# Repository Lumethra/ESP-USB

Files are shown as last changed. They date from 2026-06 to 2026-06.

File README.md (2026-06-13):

# ESP-USB

## What is this? 

This is a "wireless" USB-cable for USB devices. It can "wirelessify" (almost) any USB device with only 2 ESP32-S3's. It can be powered by 5V or even by a 3.7V LiPo battery on the senders side (the side with the USB device). I also features a minimal latency of 2ms, or sometimes even less!!!

### Features: 
- send HID-Protocols wirelessly
- pass the HID-Protocol to the PC with tinyusb
- 1 USB-C
- 1 Status-LED
- 3.7V to 5V booster
- 5V to 3.3V converter
- LiPo battery charger and protector
- 2 buttons, boot and reset
- custom USB-C-CC-Pins-handling

---

## Why? 

I got a new keyboard and wanted it to be wireless. It wasnt possible to do this from the firmware side, because it uses a rpi pico 2 as MCU and upgrading it to a rpi pico 2W wont do much because ZMK doesnt like the bluetooth feature of it. So I thought if it was possible to send the HID-reports, which the keyboard is sending constantly over 2.4Ghz, so the wifi bandwith. After some research I found out that the ESP32-S3 features USB-OTG, so it can read these reports and send them over ESP-Now, a custom "wifi" specifically for ESPs. This will reduce latency by alot. 

--- 

## How?

There are 2 ways of making this project. 1 DIY-version and 1 PCB-version. If you have 2 ESP32-S3-Wroom-1 Devboards, feel free to take the DIY road. 

### DIY:

To replicate this project with 2 ESP32-S3-Devkit-C's you simply just need to download the 2 firmwares, the senders and the recievers. The [ESP-IDF-extension](https://docs.espressif.com/projects/vscode-esp-idf-extension/en/latest/index.html) for [VS-Code](https://code.visualstudio.com/) is also required to flash the firmware. Flashing the firmware is also really easy. After sucessfully installing the ESP-IDF-extension, open the firmware of the reciever by going to the top left and selecting file > open folder > and open the folder containing the reciever firmware. Then go to the bottom bar and select UART for the flash method, its the button with the small little star. We also need to specifiy the COM-port of the ESP. Finding that out is OS-specific, but there are also alot of tutorials for this. For the IDF-Target, select ESP32-S3, since thats out device. Now we are almost finished. The last step we need to take is building and flashing the firmware. We can archieve this by clicking the fire icon a bit more on the right. This will build and flash the firmware. Now repeat this exact precess with the sender and you will have a working ESP-USB-cable. 

<details>
  <summary>
    <h4>TL;DR</h4>
  </summary> 

  - download VS-Code and the ESP-IDF extension
  - download the firmware
  - open the folder with the firmware
  - select UART for flash method
  - select the COM-Port
  - select ESP32-S3 as device
  - press the small fire to build and flash
  - repeat for 2nd device
</details>

### PCB: 

When deciding to use my custom PCB, which is smaller, we need to first order it. JLCPCB for example is a pretty good option. After having it in person, we need to connect it to our PC and hold the boot button while pressing the reset button once. After pressing the reset button we can release the boot button for now. This will set the ESP into download mode and we can flash it exactly like a ESP32-S3-Devkit-C. How this works is explained in the DIY-section above. After flashing both the reciever and the sender we need to decide on a way to power our sender (the one on the USB device side), because it needs to power our USB-device. There are 2 ways, one is connecting a LiPo battery and the other is using 2 of the 4 test pads. The LiPo battery is straight forward, but for the test pads you need 2 cables and a usb breakout board to power the pcb with 5V and GND. After all these steps you can have fun with your wireless usb cable then. 

<details>
  <summary>
    <h4>TL;DR</h4>
  </summary> 

  - order PCB
  - hold boot button
  - press reset button while boot button is hold down
  - release boot button
  - flash firmware (look [here](https://github.com/Lumethra/ESP-USB/blob/main/README.md#diy))
  
</details>

---

### Version differences

### V1:

  - small and compact
  - expensive for PCBA
  - components are exact the same as V2

### V2:

  - slightly bigger than V1
  - waaay cheaper
  - components are exact the same as V1

### V3:

  - biggest
  - adding USB-A-female connector
  - cheaper LED to save cost

---

## Renders

| PCB V1 |
| --- |
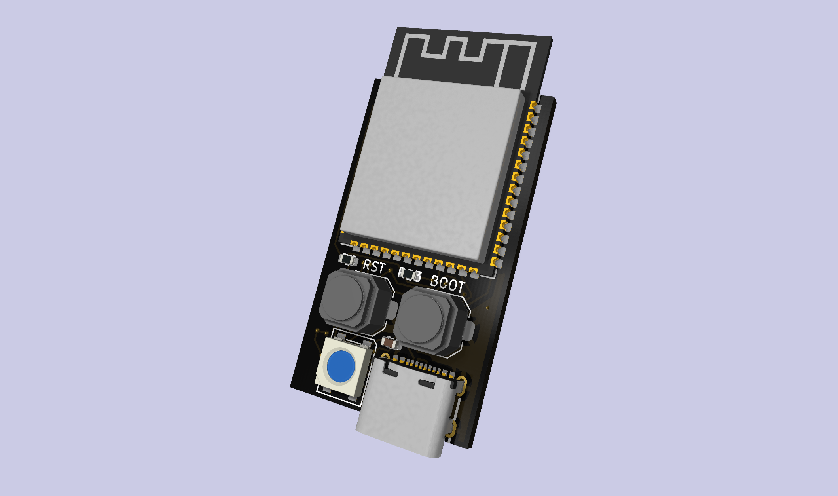
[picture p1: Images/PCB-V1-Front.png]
ESP-USB Front with Components
|  |
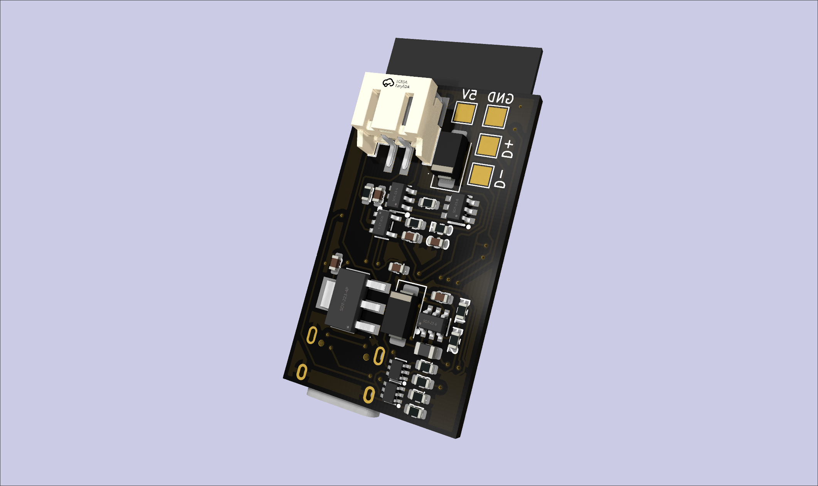
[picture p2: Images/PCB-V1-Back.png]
ESP-USB Back with Components
|  |

| PCB V2 |
| --- |
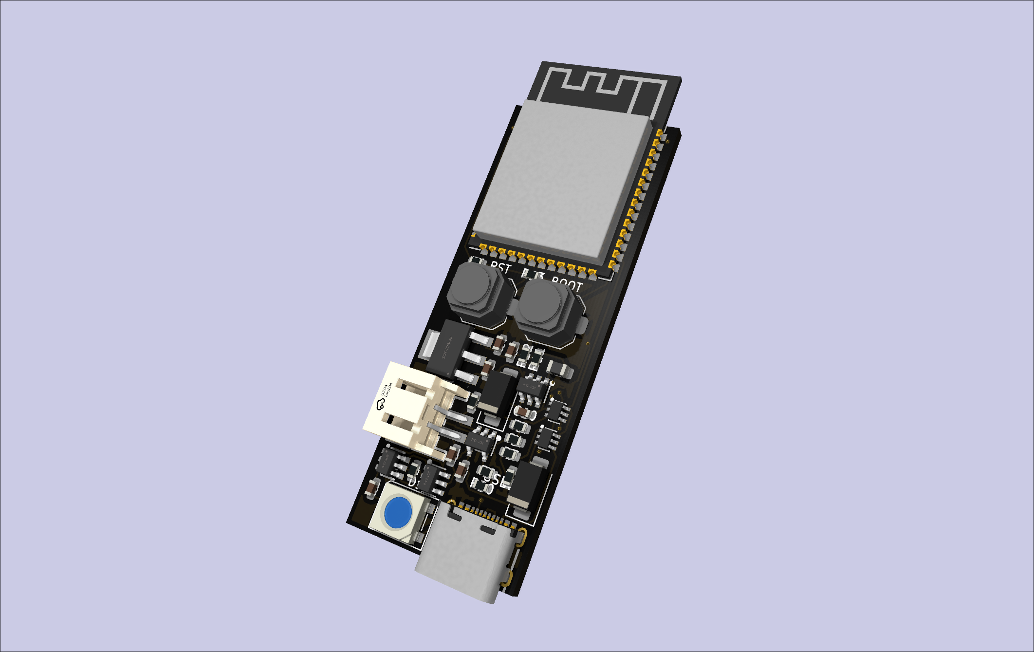
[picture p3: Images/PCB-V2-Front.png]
ESP-USB Front with Components
|  |
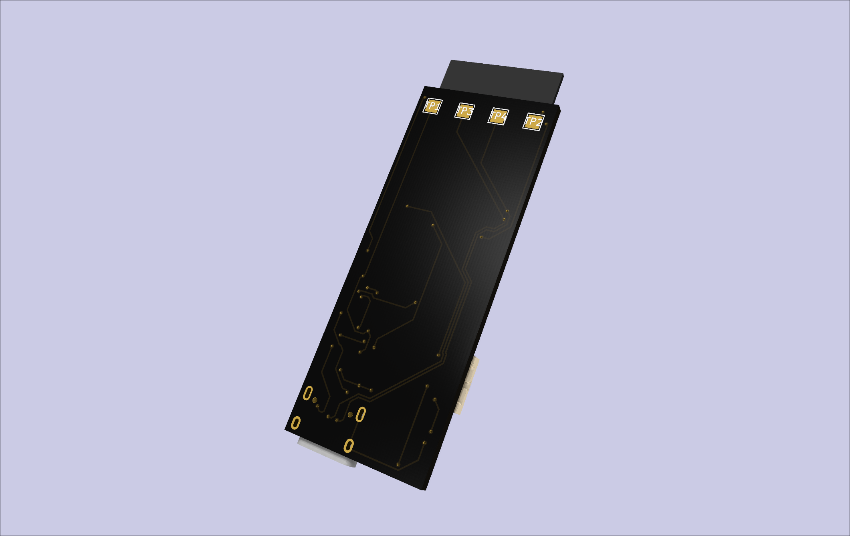
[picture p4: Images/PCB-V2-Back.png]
ESP-USB Back with Components
|  |

| PCB V3 |
| --- |
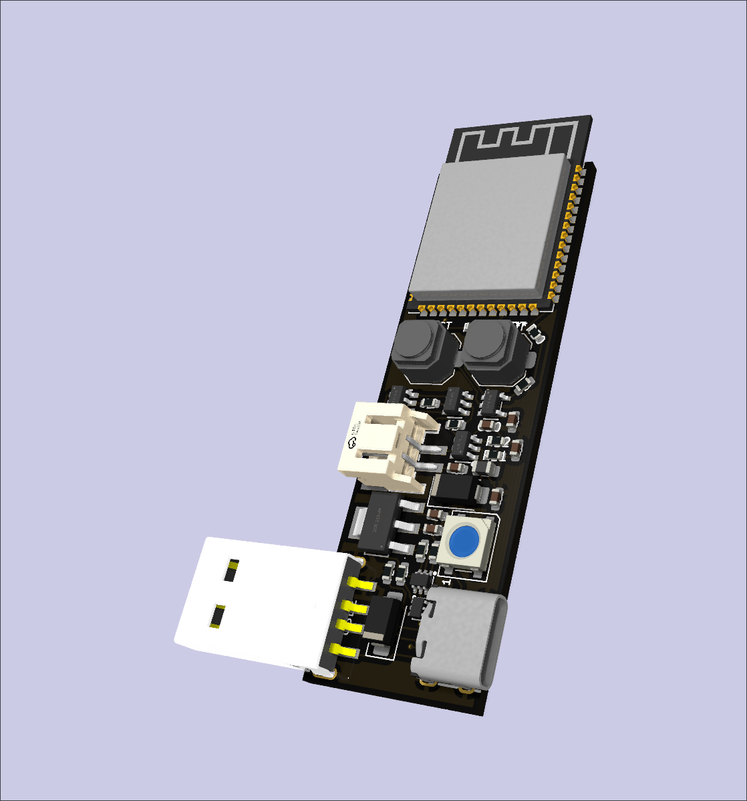
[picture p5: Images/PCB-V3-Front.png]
ESP-USB Front with Components
|  |
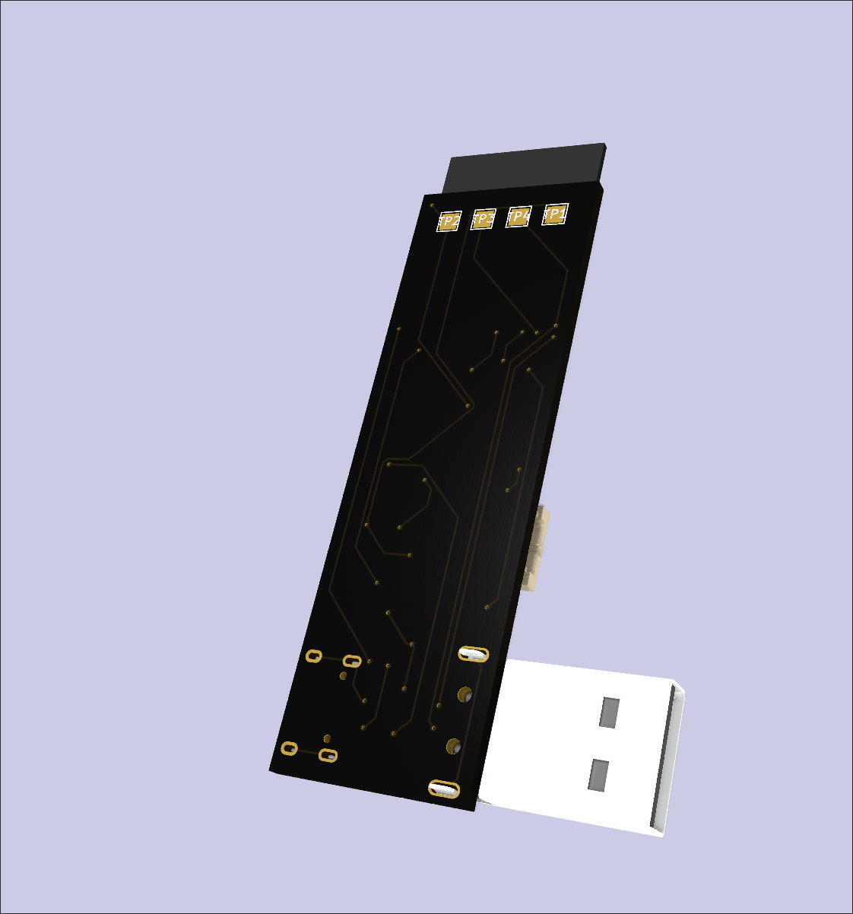
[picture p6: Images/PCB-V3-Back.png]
ESP-USB Back with Components
|  |

---

## PCB + Schematics

| PCB V1 |
| --- |
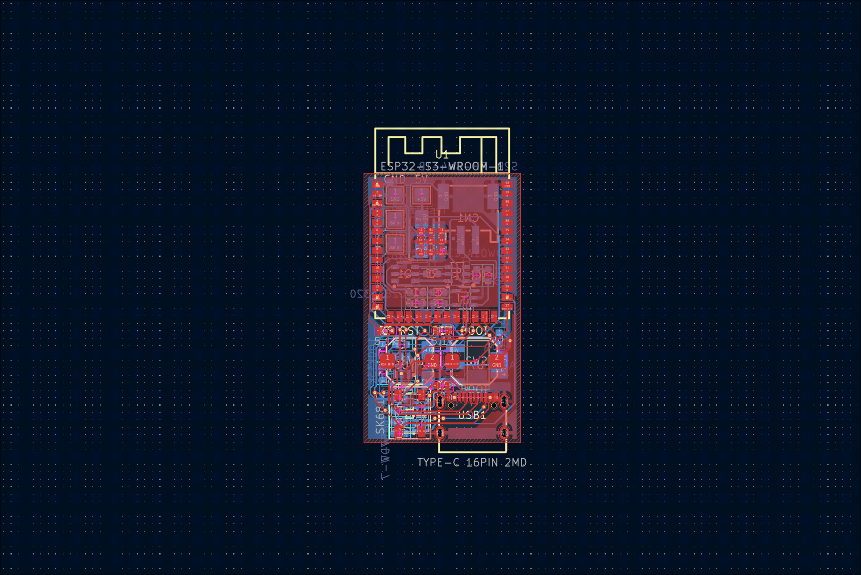
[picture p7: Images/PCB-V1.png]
|  |

| PCB V2 |
| --- |
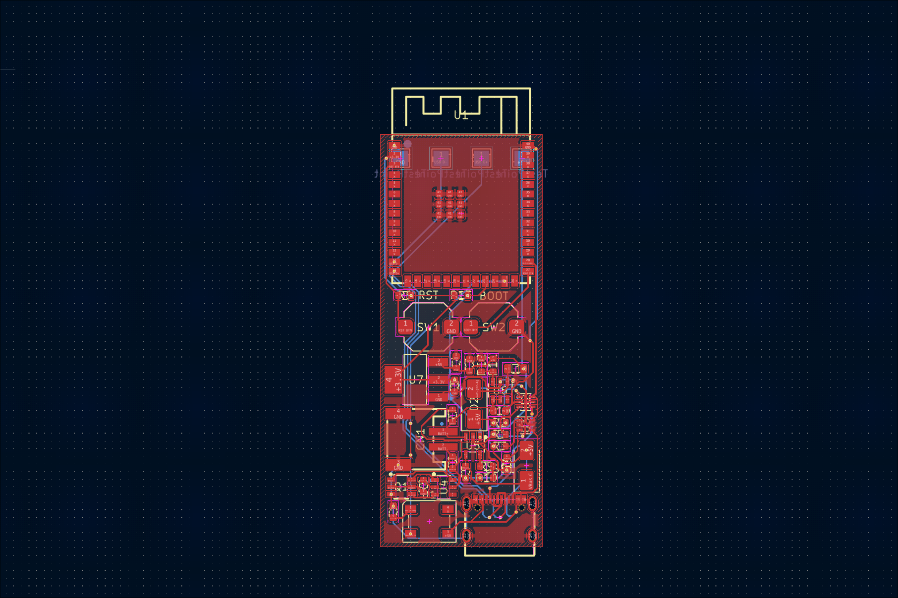
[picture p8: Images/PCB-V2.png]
|  |

| PCB V3 |
| --- |
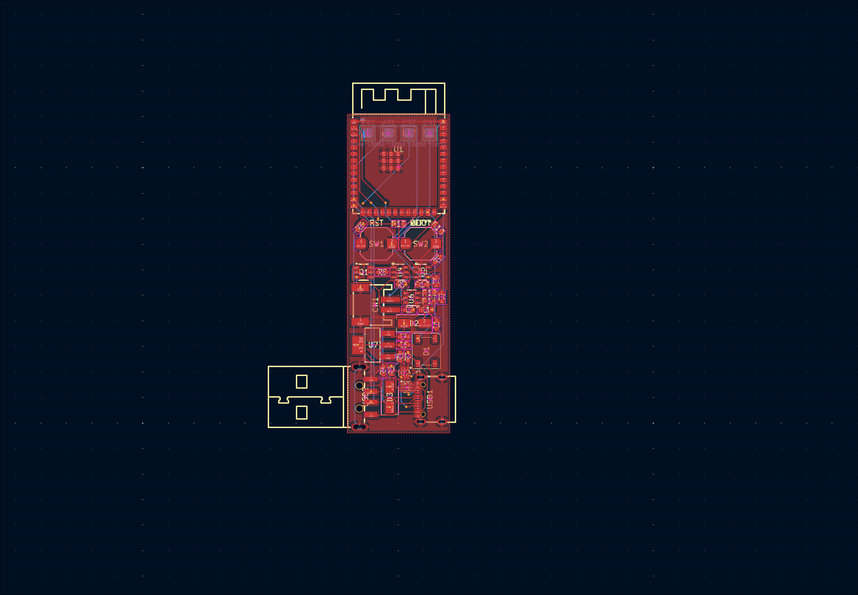
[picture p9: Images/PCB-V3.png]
|  |

| Schematics V1/V2 |
| --- |
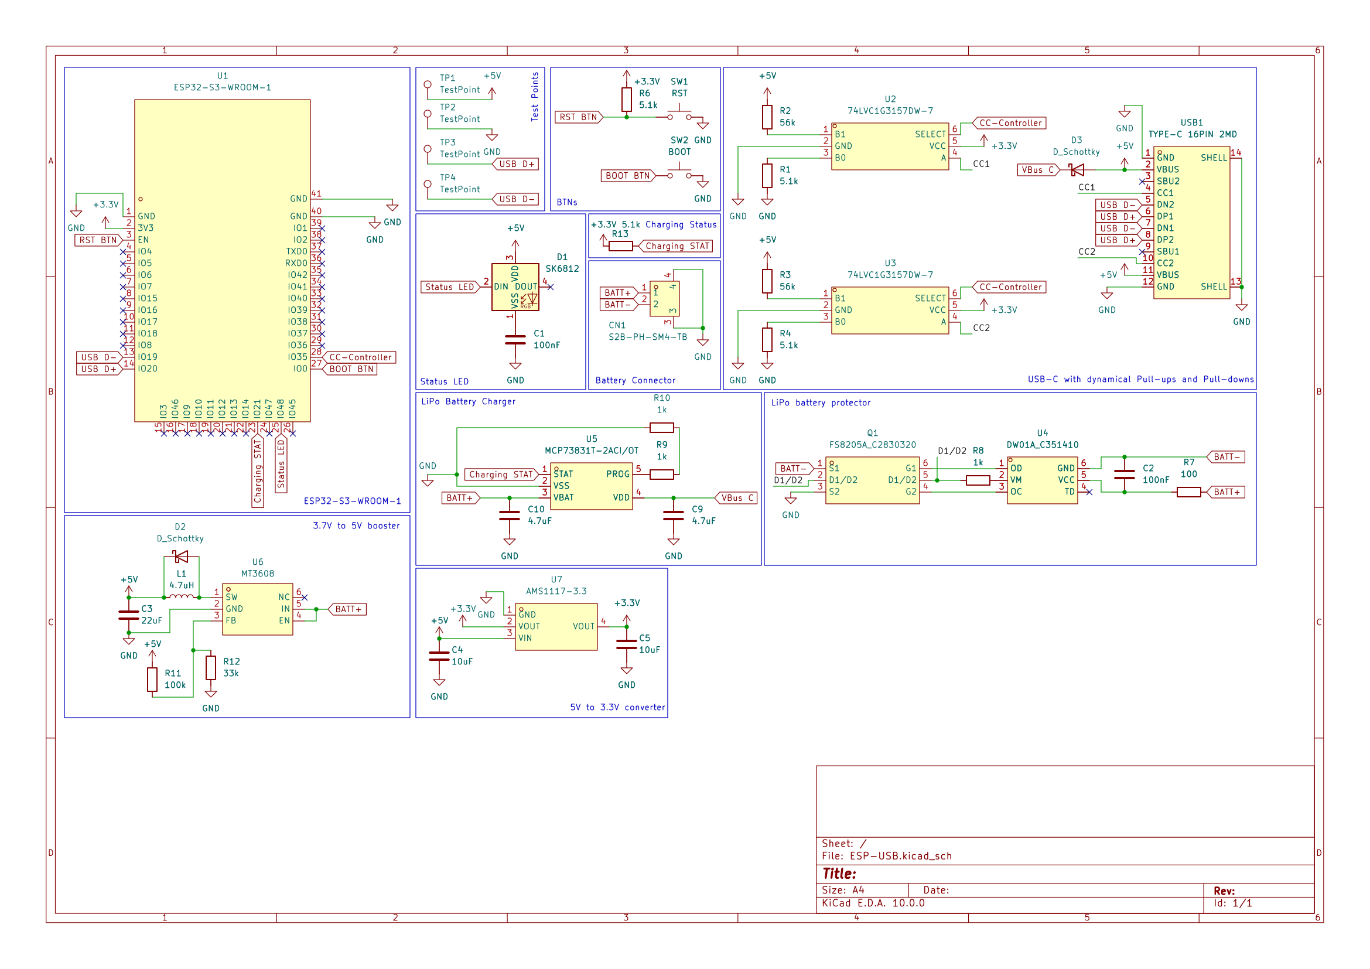
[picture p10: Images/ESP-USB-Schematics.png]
ESP-USB Schematics
|  |

| Schematics V3 |
| --- |
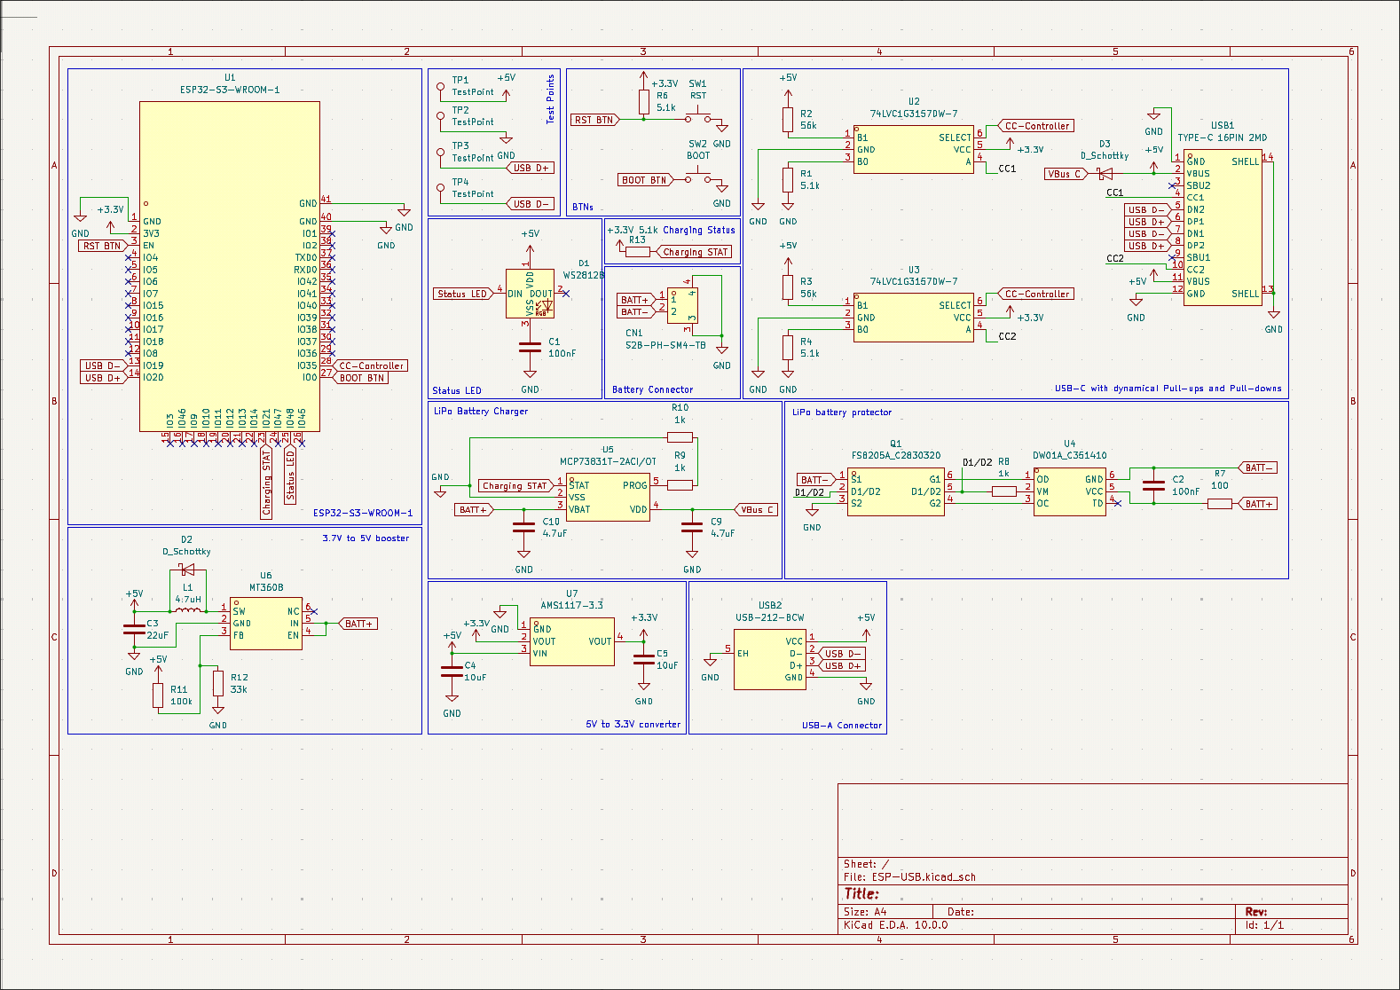
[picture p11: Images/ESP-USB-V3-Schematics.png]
ESP-USB Schematics
|  |

---

<details>
  <summary>
    <h2>Zine</h2> 
  </summary>

| Zine |
| --- |
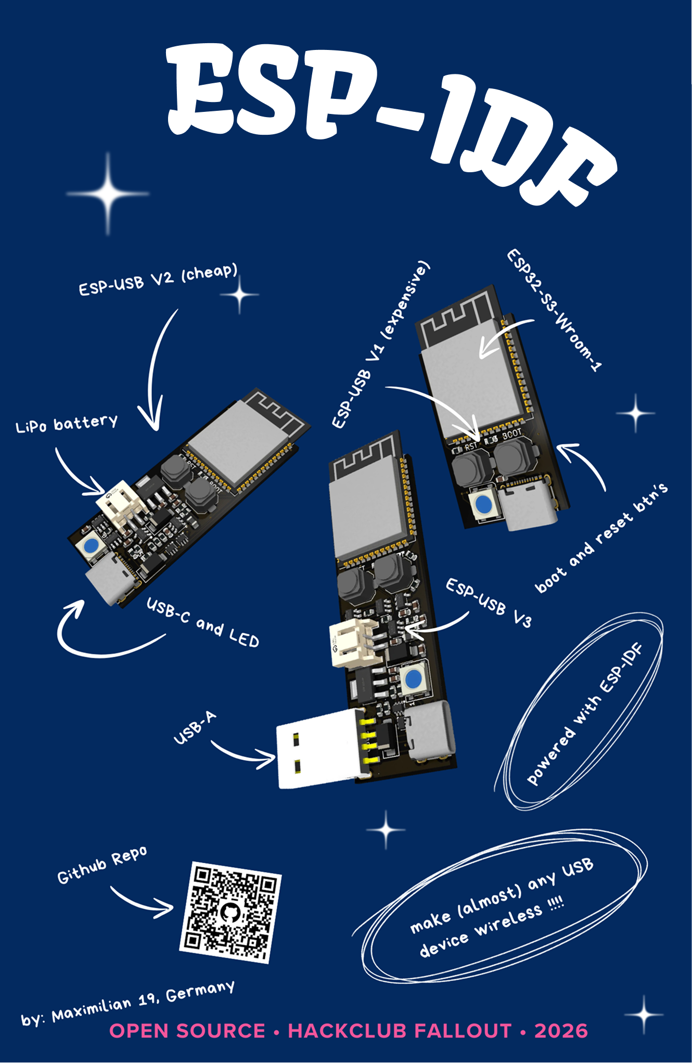
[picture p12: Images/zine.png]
ESP-USB-Zine
|  |

---
</details>

## BOM DIY

| Part | Purpose | Cost | Quantity | Total Cost | LCSC/JLCPCB Number | Link | 
| --- | --- | --- | --- | --- | --- | --- |
| ESP-32-Devkit-C | run things | $15.07 | 2 | $30.14 | ~ | [AMAZON](https://www.amazon.de/diymore-DevKitC-Development-Bluetooth-Soldered-1-piece/dp/B0CYZVQR27/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) | 
| Powered USB Hub | the usb port doesnt provide 5V and GND | ~ (already owned) | 1 | ~ (already owned) | ~ | 
| USB Device | the device u wanna make wireless | ~ (already owned) | 1 | ~ (already owned) | ~ | 
| Computer | ur computer that u wanna connect the usb device to | ~ (already owned) | 1 | ~ (already owned) | ~ | 

## BOM PCB 

| Part | Purpose | Cost | Quantity | Total Cost | LCSC/JLCPCB Number | Link | 
| --- | --- | --- | --- | --- | --- | --- |
| PCB | connecting every component | ~$2.00 | 1 (5) | ~$2.00 | ~ | [JLCPCB](https://jlcpcb.com/) |
| Capacitors 100nF | clean up power | $0.0084 | 2 | $0.0168 | C14663 | [JLCPCB](https://jlcpcb.com/partdetail/C14663) |
| Capacitors 4.7uF | cleaning power | $0.0140 | 2 | $0.0280 | C19666 | [JLCPCB](https://jlcpcb.com/partdetail/C19666) |
| Capacitor 22uF | make power clean | $0.0149 | 1 | $0.0149 | C59461 | [JLCPCB](https://jlcpcb.com/partdetail/C59461) |
| Capacitors 10uF | power gets clean | $0.0139 | 2 | $0.0278 | C19702 | [JLCPCB](https://jlcpcb.com/partdetail/C19702) |
| S2B-PH-SM4-TB | battery connector | $0.2040 | 1 | $0.2040 | C295747 | [JLCPCB](https://jlcpcb.com/partdetail/C295747) |
| SK6812 | LED | $0.0894 | 1 | $0.0894 | C5378720 | [JLCPCB](https://jlcpcb.com/partdetail/C5378720) |
| SS14 Schottky Diodes | good "one way door" | $0.0169 | 2 | $0.0338 | C2480 | [JLCPCB](https://jlcpcb.com/partdetail/C2480) |
| Inductor 4.7uH | energy storage | $0.0324 | 1 | $0.0324 | C395016 | [JLCPCB](https://jlcpcb.com/partdetail/C395016) |
| FS8205A | mosfet | $0.0575 | 1 | $0.0575 | C2830320 | [JLCPCB](https://jlcpcb.com/partdetail/C2830320) |
| Resistors 5.1k | prevent booom | $0.0016 | 4 | $0.0064 | C23186 | [JLCPCB](https://jlcpcb.com/partdetail/C23186) |
| Resistors 1k | no booom | $0.0016 | 3 | $0.0048 | C21190 | [JLCPCB](https://jlcpcb.com/partdetail/C21190) |
| Resistor 100k | aww | $0.0018 | 1 | $0.0018 | C25803 | [JLCPCB](https://jlcpcb.com/partdetail/C25803) |
| Resistor 33k | ahh, we want boom | $0.0015 | 1 | $0.0015 | C4216 | [JLCPCB](https://jlcpcb.com/partdetail/C4216) |
| Resistors 56k | no we dont | $0.0016 | 2 | $0.0032 | C23206 | [JLCPCB](https://jlcpcb.com/partdetail/C23206) |
| Resistor 100 | so resistors exist | $0.0019 | 1 | $0.0019 | C22775 | [JLCPCB](https://jlcpcb.com/partdetail/C22775) |
| RST Button | restarts the esp | $0.0206 | 1 | $0.0206 | C318884 | [JLCPCB](https://jlcpcb.com/partdetail/C318884) |
| BOOT Button | lets esp go into download mode | $0.0206 | 1 | $0.0206 | C318884 | [JLCPCB](https://jlcpcb.com/partdetail/C318884) |
| ESP32-S3-WROOM-1 | handeling firmware | $5.3893 | 1 | $5.3893 | C2913202 | [JLCPCB](https://jlcpcb.com/partdetail/C2913202) |
| 74LVC1G3157DW-7 | switch for cc pins | $0.0685 | 2 | $0.1370 | C176651 | [JLCPCB](https://jlcpcb.com/partdetail/C176651) |
| DW01A | battery protector | $0.0428 | 1 | $0.0428 | C351410 | [JLCPCB](https://jlcpcb.com/partdetail/C351410) |
| MCP73831T-2ACI/OT | battery charger | $0.8122 | 1 | $0.8122 | C424093 | [JLCPCB](https://jlcpcb.com/partdetail/C424093) |
| MT3608 | 3.7v to 5v | $0.0786 | 1 | $0.0786 | C84817 | [JLCPCB](https://jlcpcb.com/partdetail/C84817) |
| AMS1117-3.3 | 5v to 3.3v | $0.2036 | 1 | $0.2036 | C6186 | [JLCPCB](https://jlcpcb.com/partdetail/C6186) |
| USB-C Connector | connects the dongle to pcb or whatever | $0.0741 | 1 | $0.0741 | C2765186 | [JLCPCB](https://jlcpcb.com/partdetail/C2765186) |
| **Total** |  | **~$9.48**  |  | **~$9.48** <br> _+ PCBA cost_  |  |  |

---

## Contribute

Want to make it better? Found some bugs? Feel free to open a PR (pull request) and lets make the project better. ^_^
> the libraries are all imported with [easyeda2kicad](https://github.com/uPesy/easyeda2kicad.py)

--- 

## Thank you

huge thank you too all these persons helping me making this project possible, thank you helping me sanity check, thank you for all these support. 
> Thank you, <3 u all ^_^

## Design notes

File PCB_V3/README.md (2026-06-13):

# V3

Changes: 

    - adding USB-A
    - changing to a cheaper RGB-LED
        - meaning you can try solder the wroom yourself and get economics PCBA

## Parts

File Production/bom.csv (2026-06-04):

Name | Designator | Footprint | Quantity | Value | Price | LCSC Part # | Purchase Link
Capacitors 100nF | C1, C2 | 0603 | 2 | 100nF | $0.0032 | C14663 | https://jlcpcb.com/partdetail/C14663
Capacitors 4.7uF | C9, C10 | 0603 | 2 | 4.7uF | $0.0110 | C19666 | https://jlcpcb.com/partdetail/C19666
Capacitor 22uF | C3 | 0603 | 1 | 22uF | $0.0100 | C59461 | https://jlcpcb.com/partdetail/C59461
Capacitors 10uF | C4, C5 | 0603 | 2 | 10uF | $0.0100 | C19702 | https://jlcpcb.com/partdetail/C19702
S2B-PH-SM4-TB | CN1 | CONN-SMD_P2.00_S2B-PH-SM4-TB-LF-SN | 1 | S2B-PH-SM4-TB | $0.2014 | C295747 | https://jlcpcb.com/partdetail/C295747
SK6812 | D1 | LED_SK6812_PLCC4_5.0x5.0mm_P3.2mm | 1 | SK6812 | $0.1000 | C5378720 | https://jlcpcb.com/partdetail/C5378720
SS14 Schottky Diodes | D2, D3 | D_SMA | 2 | D_Schottky | $0.0200 | C2480 | https://jlcpcb.com/partdetail/C2480
Inductor 4.7uH | L1 | 0805 | 1 | 4.7uH | $0.0500 | C395016 | https://jlcpcb.com/partdetail/C395016
FS8205A | Q1 | SOT-23-6_L2.9-W1.6-P0.95-LS2.8-BR | 1 | FS8205A_C2830320 | $0.0470 | C2830320 | https://jlcpcb.com/partdetail/C2830320
Resistors 5.1k | R1, R4, R6, R13 | 0603 | 4 | 5.1k | $0.0016 | C23186 | https://jlcpcb.com/partdetail/C23186
Resistors 1k | R8, R9, R10 | 0603 | 3 | 1k | $0.0016 | C21190 | https://jlcpcb.com/partdetail/C21190
Resistor 100k | R11 | 0603 | 1 | 100k | $0.0016 | C25803 | https://jlcpcb.com/partdetail/C25803
Resistor 33k | R12 | 0603 | 1 | 33k | $0.0016 | C4216 | https://jlcpcb.com/partdetail/C4216
Resistors 56k | R2, R3 | 0603 | 2 | 56k | $0.0016 | C23206 | https://jlcpcb.com/partdetail/C23206
Resistor 100 | R7 | 0603 | 1 | 100 | $0.0016 | C22775 | https://jlcpcb.com/partdetail/C22775
RST Button | SW1 | SW_Push_1TS009xxxx-xxxx-xxxx_6x6x5mm | 1 | RST | $0.0500 | C318884 | https://jlcpcb.com/partdetail/C318884
BOOT Button | SW2 | SW_Push_1TS009xxxx-xxxx-xxxx_6x6x5mm | 1 | BOOT | $0.0500 | C318884 | https://jlcpcb.com/partdetail/C318884
ESP32-S3-WROOM-1 | U1 | WIRELM-SMD_ESP32-S3-WROOM-1 | 1 | ESP32-S3-WROOM-1 | $4.0000 | C2913202 | https://jlcpcb.com/partdetail/C2913202
74LVC1G3157DW-7 | U2, U3 | SOT-363-6_L2.2-W1.3-P0.65-LS2.1-BL | 2 | 74LVC1G3157DW-7 | $0.0500 | C176651 | https://jlcpcb.com/partdetail/C176651
DW01A | U4 | SOT-23-6_L2.9-W1.6-P0.95-LS2.8-BL | 1 | DW01A_C351410 | $0.0426 | C351410 | https://jlcpcb.com/partdetail/C351410
MCP73831T-2ACI/OT | U5 | SOT-23-5_L3.0-W1.7-P0.95-LS2.8-BL | 1 | MCP73831T-2ACI/OT | $0.7585 | C424093 | https://jlcpcb.com/partdetail/C424093
MT3608 | U6 | SOT-23-6_L2.9-W1.6-P0.95-LS2.8-BL | 1 | MT3608 | $0.0667 | C84817 | https://jlcpcb.com/partdetail/C84817
AMS1117-3.3 | U7 | SOT-223-3_L6.5-W3.4-P2.30-LS7.0-BR | 1 | AMS1117-3.3 | $0.1120 | C6186 | https://jlcpcb.com/partdetail/C6186
USB-C Connector | USB1 | USB-C-SMD_TYPE-C-6PIN-2MD-073 | 1 | TYPE-C 16PIN 2MD | $0.0740 | C2765186 | https://jlcpcb.com/partdetail/C2765186

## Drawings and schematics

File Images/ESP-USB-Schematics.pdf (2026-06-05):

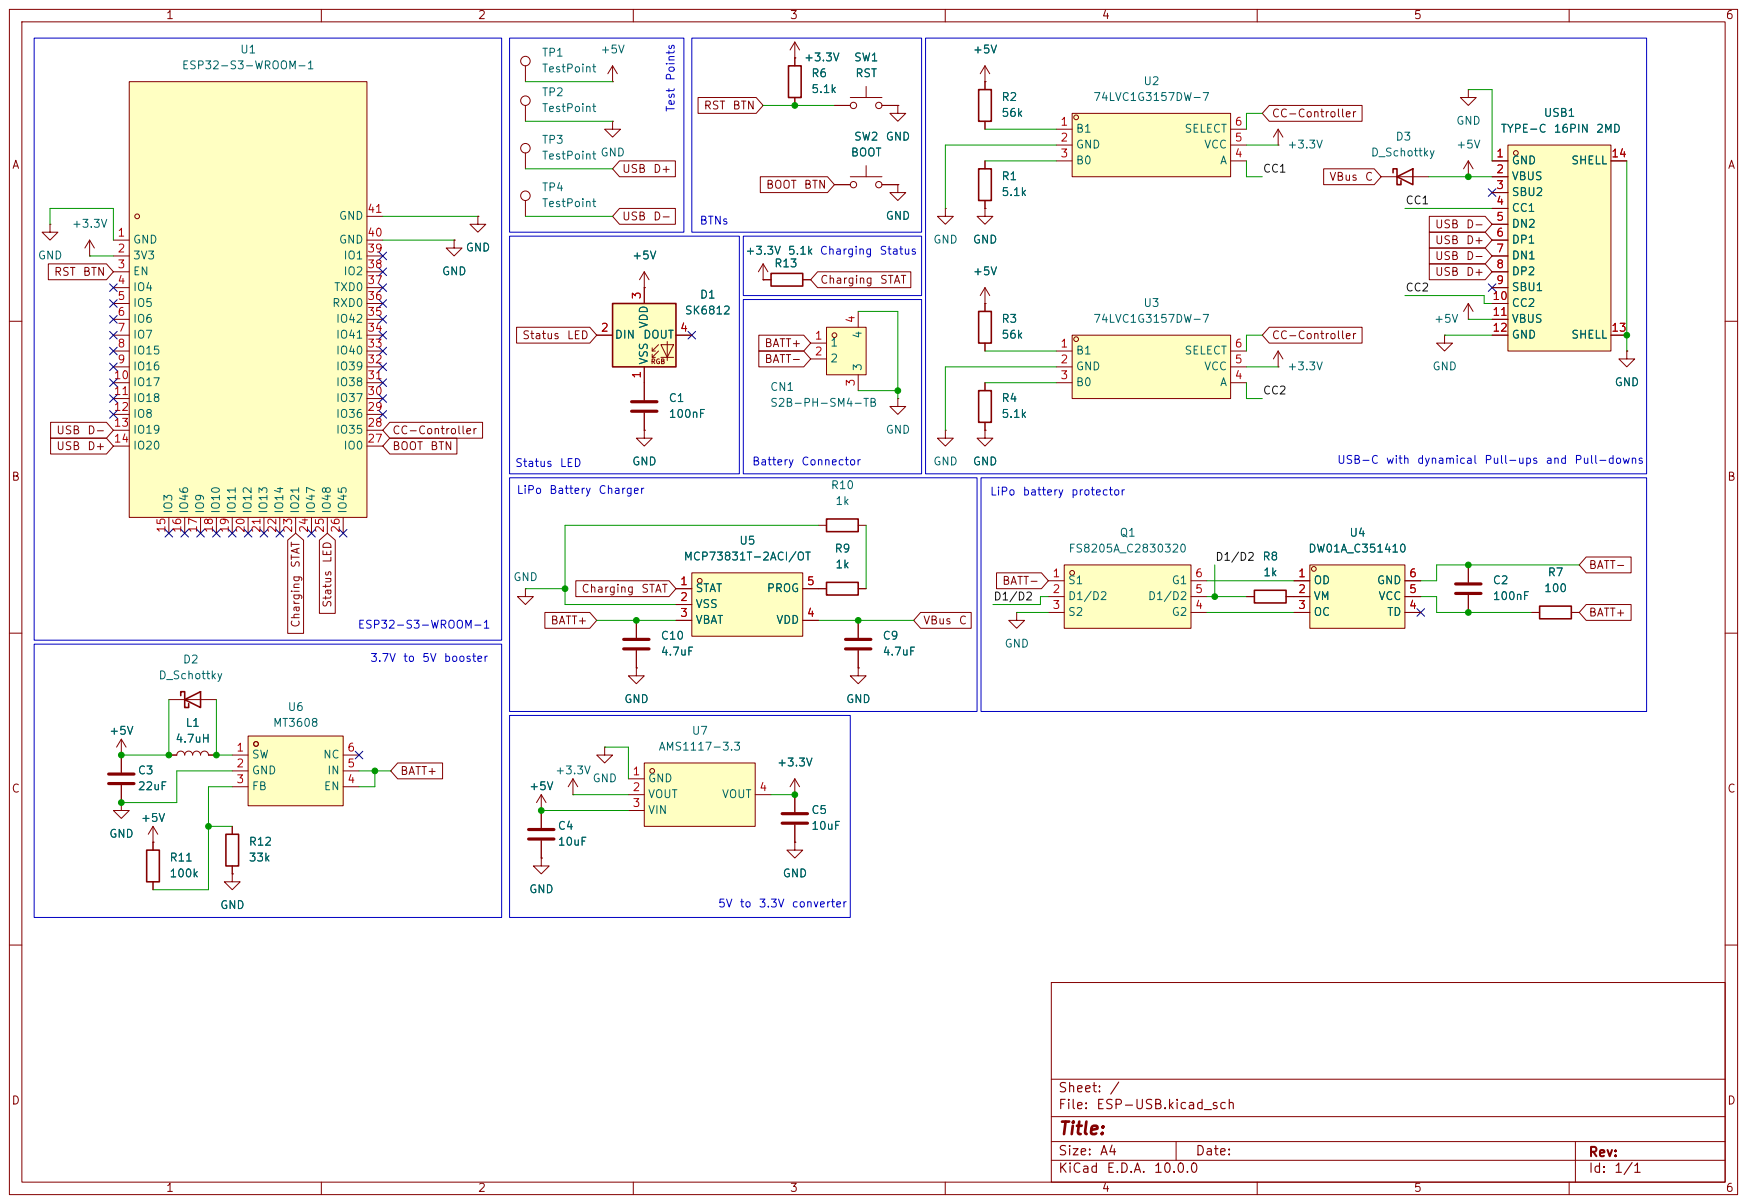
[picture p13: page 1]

USB D- Status LED Charging STAT

Charging Status Battery Connector LiPo Battery Charger

Size: A4 | Rev:
KiCad E.D.A. 10.0.0 | Id: 1/1

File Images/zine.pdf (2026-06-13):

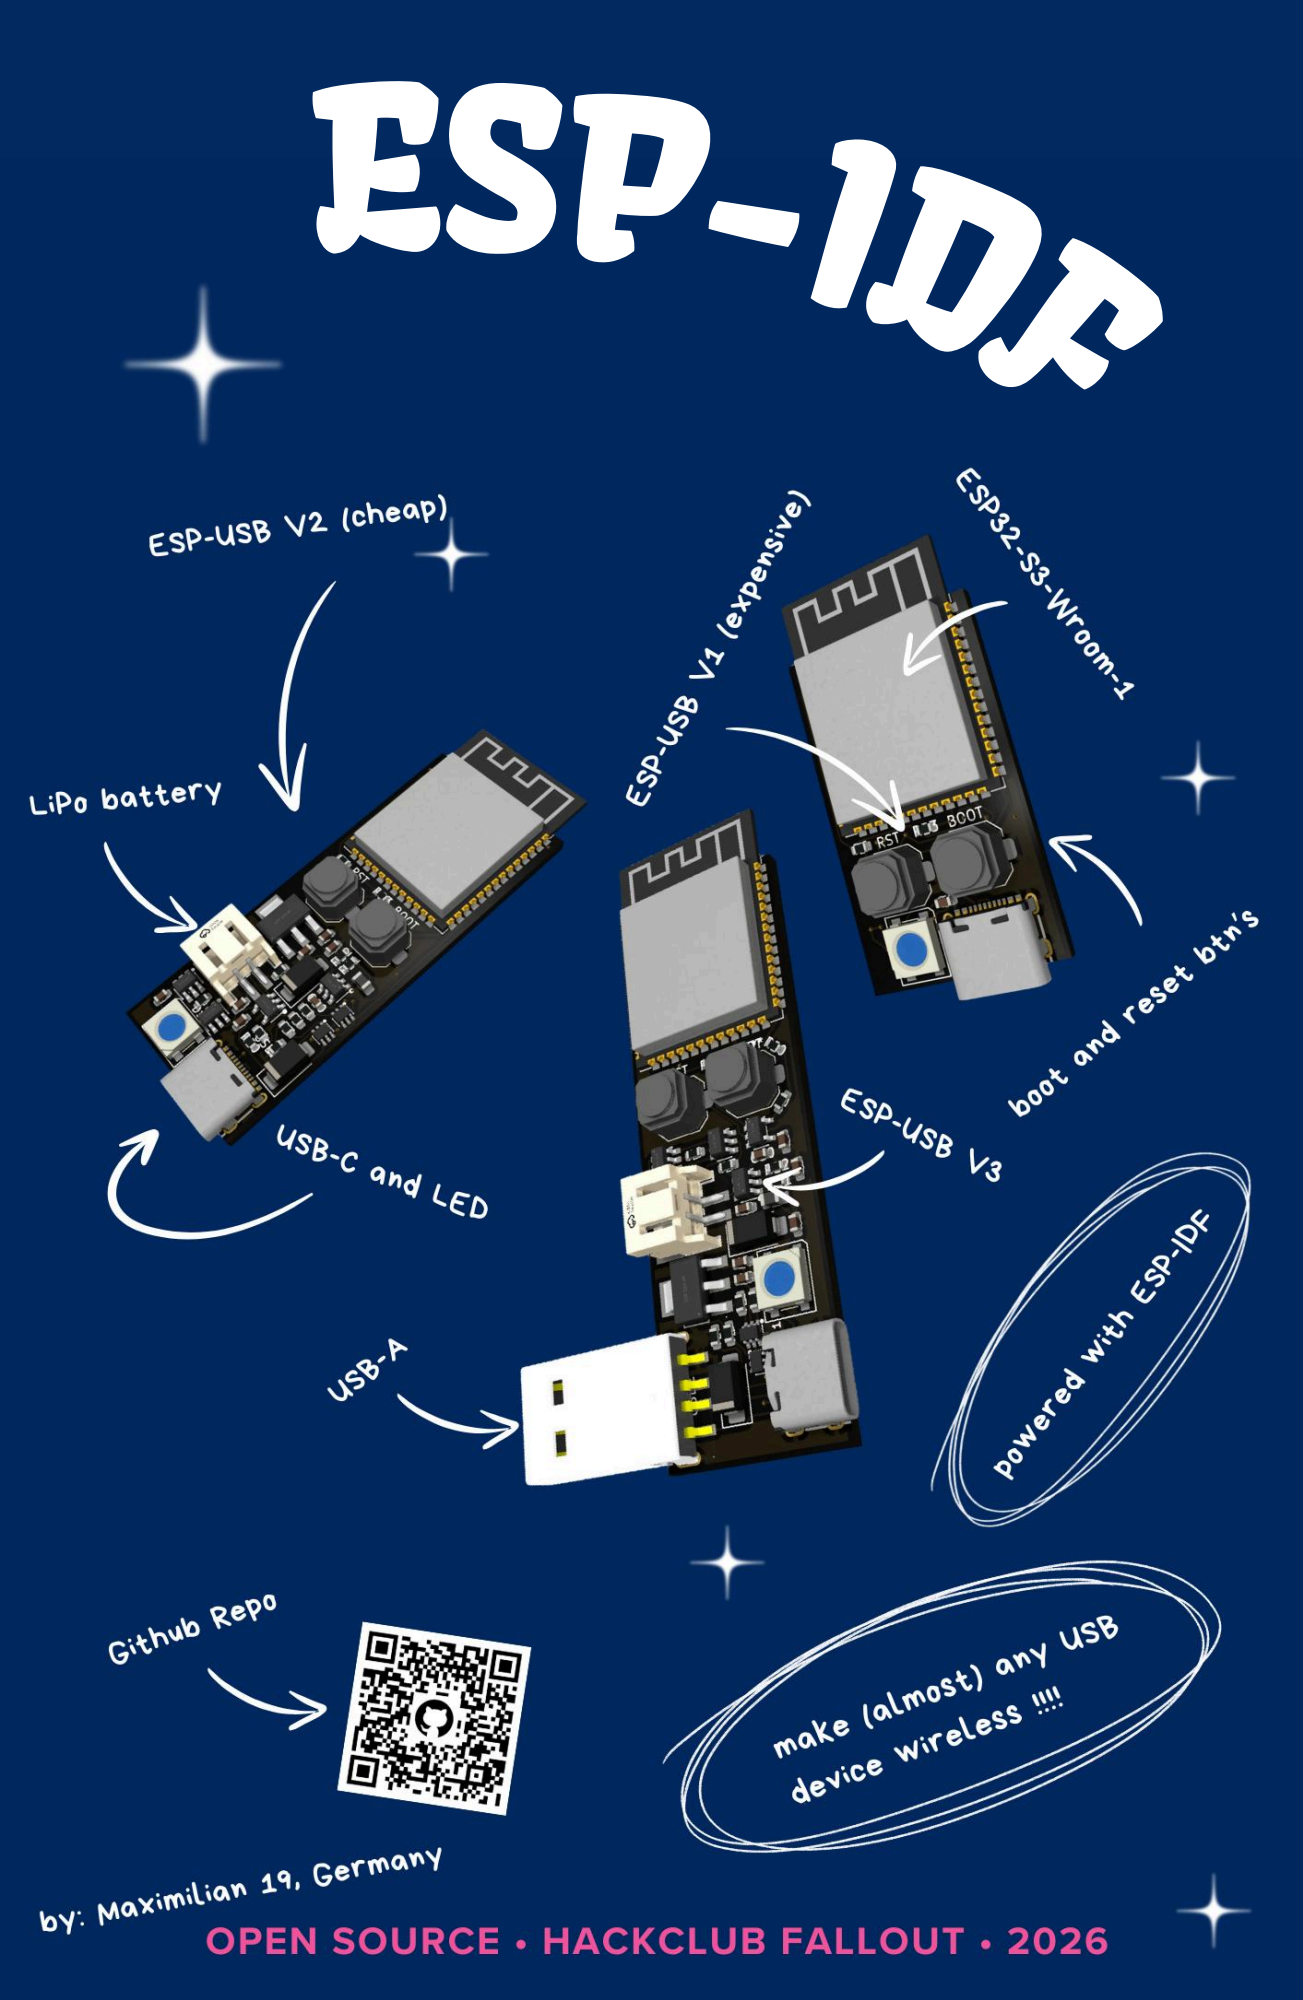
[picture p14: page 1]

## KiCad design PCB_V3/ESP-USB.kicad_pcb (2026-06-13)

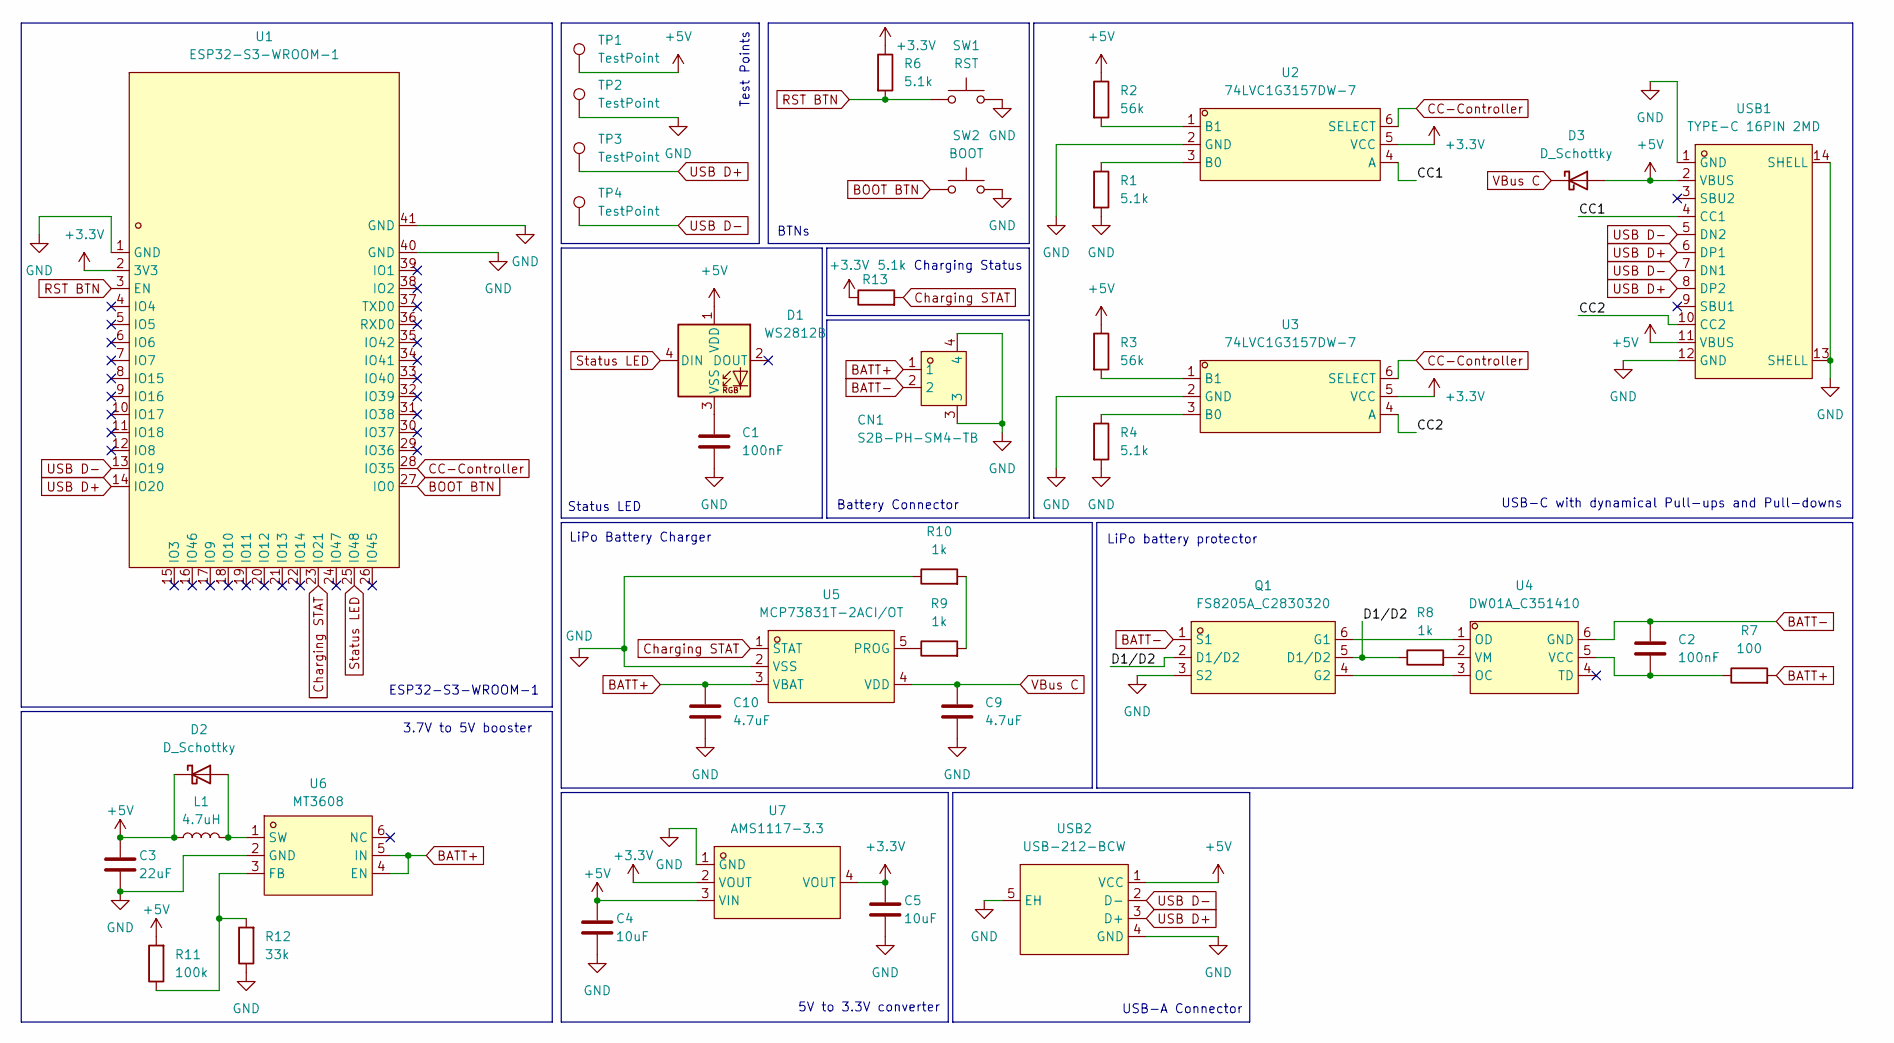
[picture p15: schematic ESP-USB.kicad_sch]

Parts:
C1, C2: 100nF; C_0603_1608Metric; LCSC Part C14663
C3: 22uF; C_0603_1608Metric; LCSC Part C59461
C4, C5: 10uF; C_0603_1608Metric; LCSC Part C19702
C9, C10: 4.7uF; C_0603_1608Metric; LCSC Part C19666
CN1: S2B-PH-SM4-TB; CONN-SMD_P2.00_S2B-PH-SM4-TB-LF-SN; MPN S2B-PH-SM4-TB(LF)(SN); LCSC Part C295747
D1: WS2812B; LED_WS2812B_PLCC4_5.0x5.0mm_P3.2mm; LCSC Part C42417498
D2, D3: D_Schottky; D_SMA; LCSC Part C2480
L1: 4.7uH; L_0805_2012Metric; LCSC Part C395016
Q1: FS8205A_C2830320; SOT-23-6_L2.9-W1.6-P0.95-LS2.8-BR; MPN FS8205A; LCSC Part C2830320
R1, R4, R6, R13: 5.1k; R_0603_1608Metric; LCSC Part C23186
R2, R3: 56k; R_0603_1608Metric; LCSC Part C23206
R7: 100; R_0603_1608Metric; LCSC Part C22775
R8, R9, R10: 1k; R_0603_1608Metric; LCSC Part C21190
R11: 100k; R_0603_1608Metric; LCSC Part C25803
R12: 33k; R_0603_1608Metric; LCSC Part C4216
SW1: RST; SW_Push_1TS009xxxx-xxxx-xxxx_6x6x5mm; LCSC Part C318884
SW2: BOOT; SW_Push_1TS009xxxx-xxxx-xxxx_6x6x5mm; LCSC Part C318884
TP1, TP2, TP3, TP4: TestPoint; TestPoint_Pad_2.0x2.0mm
U1: ESP32-S3-WROOM-1; WIRELM-SMD_ESP32-S3-WROOM-1; MPN ESP32-S3-WROOM-1-N16R8; LCSC Part C2913202
U2, U3: 74LVC1G3157DW-7; SOT-363-6_L2.2-W1.3-P0.65-LS2.1-BL; MPN 74LVC1G3157DW-7; LCSC Part C176651
U4: DW01A_C351410; SOT-23-6_L2.9-W1.6-P0.95-LS2.8-BL; MPN DW01A; LCSC Part C351410
U5: MCP73831T-2ACI/OT; SOT-23-5_L3.0-W1.7-P0.95-LS2.8-BL; MPN MCP73831T-2ACI/OT; LCSC Part C424093
U6: MT3608; SOT-23-6_L2.9-W1.6-P0.95-LS2.8-BL; MPN MT3608; LCSC Part C84817
U7: AMS1117-3.3; SOT-223-3_L6.5-W3.4-P2.30-LS7.0-BR; MPN AMS1117-3.3; LCSC Part C6186
USB1: TYPE-C 16PIN 2MD; USB-C-SMD_TYPE-C-6PIN-2MD-073; MPN TYPE-C 16PIN 2MD(073); LCSC Part C2765186
USB2: USB-212-BCW; USB-A-SMD_USB-212-BCW; MPN USB-212-BCW; LCSC Part C720521

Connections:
+3.3V: C5.1, R6.1, R13.1, U1.2 (3V3), U2.5 (VCC), U3.5 (VCC), U7.2 (VOUT), U7.4 (VOUT)
+5V: C3.1, C4.1, D1.1 (VDD), D2.1 (K), D3.2 (A), L1.1, R2.1, R3.1, R11.2, TP1.1 (1_1), U7.3 (VIN), USB1.2 (VBUS), USB1.11 (VBUS), USB2.1 (VCC)
/CC1: U2.4 (A), USB1.4 (CC1)
/CC2: U3.4 (A), USB1.10 (CC2)
/D1/D2: Q1.2 (D1/D2), Q1.5 (D1/D2), R8.1
BATT+: C10.1, CN1.1, R7.2, U5.3 (VBAT), U6.4 (EN), U6.5 (IN)
BATT-: C2.1, CN1.2, Q1.1 (S1), U4.6 (GND)
BOOT BTN: SW2.1, U1.27 (IO0)
CC-Controller: U1.28 (IO35), U2.6 (SELECT), U3.6 (SELECT)
Charging STAT: R13.2, U1.23 (IO21), U5.1 (STAT)
GND: C1.2, C3.2, C4.2, C5.2, C9.2, C10.2, CN1.3, CN1.4, Q1.3 (S2), R1.2, R4.2, R10.1, R12.1, SW1.2, SW2.2, TP2.1 (1_1), U1.1 (GND), U1.40 (GND), U1.41 (GND), U2.2 (GND), U3.2 (GND), U5.2 (VSS), U6.2 (GND), U7.1 (GND), USB1.1 (GND), USB1.12 (GND), USB1.13 (SHELL), USB1.14 (SHELL), USB2.4 (GND), USB2.5 (EH)
unnamed: C1.1, D1.3 (VSS)
unnamed: D2.2 (A), L1.2, U6.1 (SW)
unnamed: Q1.6 (G1), U4.1 (OD)
unnamed: Q1.4 (G2), U4.3 (OC)
unnamed: R9.2, R10.2
unnamed: R1.1, U2.3 (B0)
unnamed: R2.2, U2.1 (B1)
unnamed: R4.1, U3.3 (B0)
unnamed: R3.2, U3.1 (B1)
unnamed: C2.2, R7.1, U4.5 (VCC)
unnamed: R8.2, U4.2 (VM)
unnamed: R9.1, U5.5 (PROG)
unnamed: R11.1, R12.2, U6.3 (FB)
RST BTN: R6.2, SW1.1, U1.3 (EN)
Status LED: D1.4 (DIN), U1.25 (IO48)
USB D+: TP3.1 (1_1), U1.14 (IO20), USB1.6 (DP1), USB1.8 (DP2), USB2.3 (D+)
USB D-: TP4.1 (1_1), U1.13 (IO19), USB1.5 (DN2), USB1.7 (DN1), USB2.2 (D-)
VBus C: C9.1, D3.1 (K), U5.4 (VDD)

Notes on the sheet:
5V to 3.3V converter
Test Points
USB-C with dynamical Pull-ups and Pull-downs
Charging Status
LiPo Battery Charger
BTNs
LiPo battery protector
ESP32-S3-WROOM-1
USB-A Connector
3.7V to 5V booster
Status LED
Battery Connector

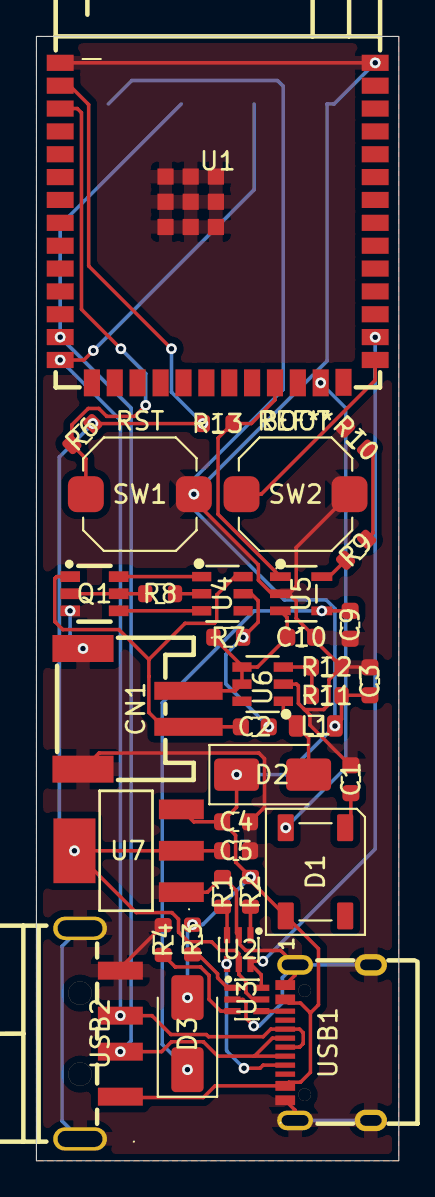
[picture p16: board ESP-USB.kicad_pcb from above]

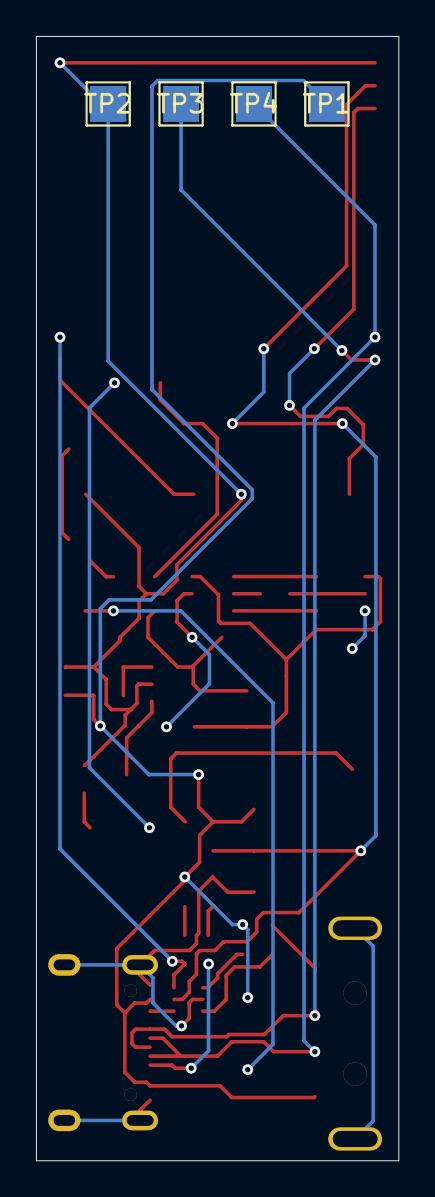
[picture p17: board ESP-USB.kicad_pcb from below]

Board: 2 copper layers, 20.1 x 62.5 mm, 40 parts (4 on the bottom side), 29 nets.

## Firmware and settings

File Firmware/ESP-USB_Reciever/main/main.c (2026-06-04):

#include <stdio.h>
#include <string.h>
#include "esp_log.h"
#include "esp_now.h"
#include "esp_wifi.h"
#include "nvs_flash.h"
#include "freertos/FreeRTOS.h"
#include "freertos/task.h"
#include "tinyusb.h"
#include "tinyusb_default_config.h"
#include "class/hid/hid_device.h"
#include "device/usbd.h"

static const char *TAG = "receiver";

#define PKT_DEVICE_DESC 0xFD
#define PKT_CONFIG_DESC 0xFE
#define PKT_HID_REPORT  0xFF

#define MAX_CONFIG_DESC_SIZE 1024

static const char *hid_string_descriptor[5] = {
    (char[]){0x09, 0x04},
    "ESP-USB",
    "ESP-USB HID",
    "123456",
    "ESP-USB Device",
};

static const uint8_t fallback_report_desc[] = {
    TUD_HID_REPORT_DESC_KEYBOARD(HID_REPORT_ID(HID_ITF_PROTOCOL_KEYBOARD)),
};

#define FALLBACK_DESC_TOTAL_LEN (TUD_CONFIG_DESC_LEN + TUD_HID_DESC_LEN)
static const uint8_t fallback_config_desc[] = {
    TUD_CONFIG_DESCRIPTOR(1, 1, 0, FALLBACK_DESC_TOTAL_LEN,
                          TUSB_DESC_CONFIG_ATT_REMOTE_WAKEUP, 100),
    TUD_HID_DESCRIPTOR(0, 4, false, sizeof(fallback_report_desc), 0x81, 16, 10),
};

static tusb_desc_device_t received_device_desc = {0};
static uint8_t received_config_desc[MAX_CONFIG_DESC_SIZE] = {0};
static uint16_t received_config_len = 0;
static uint8_t config_chunks_received = 0;
static uint8_t config_chunks_total = 0;
static uint8_t received_report_desc[249] = {0};
static size_t received_report_desc_len = 0;
static uint8_t built_config_desc[TUD_CONFIG_DESC_LEN + TUD_HID_DESC_LEN];

static bool device_desc_ready = false;
static bool config_desc_ready = false;
static bool report_desc_ready = false;
static bool tusb_installed = false;
static TaskHandle_t main_task_handle = NULL;

uint8_t const *tud_hid_descriptor_report_cb(uint8_t instance)
{
    return received_report_desc_len > 0 ? received_report_desc : fallback_report_desc;
}

uint16_t tud_hid_get_report_cb(uint8_t instance, uint8_t report_id,
                                hid_report_type_t report_type, uint8_t *buffer,
                                uint16_t reqlen)
{
    return 0;
}

void tud_hid_set_report_cb(uint8_t instance, uint8_t report_id,
                            hid_report_type_t report_type,
                            uint8_t const *buffer, uint16_t bufsize)
{
}

static void do_install_tusb(bool use_real_desc)
{
    if (tusb_installed) {
        ESP_LOGI(TAG, "Uninstalling TinyUSB...");
        tinyusb_driver_uninstall();
        tusb_installed = false;
        vTaskDelay(pdMS_TO_TICKS(500));
    }

    tinyusb_config_t tusb_cfg = TINYUSB_DEFAULT_CONFIG();
    tusb_cfg.descriptor.string = hid_string_descriptor;
    tusb_cfg.descriptor.string_count =
        sizeof(hid_string_descriptor) / sizeof(hid_string_descriptor[0]);

    if (use_real_desc) {
        received_device_desc.bMaxPacketSize0 = 64;
        tusb_cfg.descriptor.device = &received_device_desc;
            
        uint16_t total_len = TUD_CONFIG_DESC_LEN + TUD_HID_DESC_LEN;
        const uint8_t cfg[] = {
            TUD_CONFIG_DESCRIPTOR(1, 1, 0, total_len, TUSB_DESC_CONFIG_ATT_REMOTE_WAKEUP, 100),
            TUD_HID_DESCRIPTOR(0, 4, false, received_report_desc_len, 0x81, 16, 10),
        };
        memcpy(built_config_desc, cfg, sizeof(cfg));
        tusb_cfg.descriptor.full_speed_config = built_config_desc;

        ESP_LOGI(TAG, "Installing TinyUSB with real VID/PID and report desc (%d bytes)",
                 (int)received_report_desc_len);
    } else {
        tusb_cfg.descriptor.device = NULL;
        tusb_cfg.descriptor.full_speed_config = fallback_config_desc;
        ESP_LOGI(TAG, "Installing TinyUSB with fallback descriptor");
    }

    esp_err_t err = tinyusb_driver_install(&tusb_cfg);
    if (err != ESP_OK) {
        ESP_LOGE(TAG, "TinyUSB install failed: %s", esp_err_to_name(err));
        return;
    }
    tusb_installed = true;
}

static void on_recv(const esp_now_recv_info_t *info, const uint8_t *data, int len)
{
    if (data[0] == PKT_DEVICE_DESC && len == 19) {
        ESP_LOGI(TAG, "Received device descriptor");
        memcpy(&received_device_desc, &data[1], sizeof(tusb_desc_device_t));
        device_desc_ready = true;
        config_desc_ready = false;
        report_desc_ready = false;
        config_chunks_received = 0;
        config_chunks_total = 0;
        received_config_len = 0;
        received_report_desc_len = 0;
        return;
    }

    if (data[0] == PKT_CONFIG_DESC && len >= 4) {
        uint8_t chunk_idx = data[1];
        uint8_t total_chunks = data[2];
        uint8_t chunk_data_len = len - 3;
        uint16_t offset = chunk_idx * 247;

        if (chunk_idx == 0) {
            config_chunks_received = 0;
            config_chunks_total = total_chunks;
            received_config_len = 0;
        }

        if (offset + chunk_data_len <= MAX_CONFIG_DESC_SIZE) {
            memcpy(&received_config_desc[offset], &data[3], chunk_data_len);
            received_config_len += chunk_data_len;
            config_chunks_received++;
            ESP_LOGI(TAG, "Config chunk %d/%d received", chunk_idx + 1, total_chunks);

            if (config_chunks_received == config_chunks_total) {
                ESP_LOGI(TAG, "Config descriptor complete (%d bytes)", received_config_len);
                config_desc_ready = true;
                if (device_desc_ready && report_desc_ready) {
                    xTaskNotifyGive(main_task_handle);
                }
            }
        }
        return;
    }

    if (data[0] == PKT_HID_REPORT) {
        uint8_t proto = data[1];
        size_t desc_len = len - 2;
        const char *proto_name = proto == 1 ? "keyboard" : proto == 2 ? "mouse" : "vendor";
        ESP_LOGI(TAG, "Received HID report descriptor proto=%s (%d bytes)", proto_name, (int)desc_len);

        if (proto == 0) return;
        if (!report_desc_ready) {
            memcpy(received_report_desc, &data[2], desc_len);
            received_report_desc_len = desc_len;
            report_desc_ready = true;
            if (device_desc_ready && config_desc_ready) {
                xTaskNotifyGive(main_task_handle);
            }
        }
        return;
    }

    ESP_LOGI(TAG, "HID report (%d bytes): %02X %02X %02X %02X %02X %02X %02X %02X",
             len, data[0], data[1], data[2], data[3], data[4], data[5],
             data[6], data[7]);

    if (tusb_installed && tud_mounted()) {
        tud_hid_n_report(0, 0, data, len);
    }
}

void app_main(void)
{
    main_task_handle = xTaskGetCurrentTaskHandle();

    nvs_flash_init();
    esp_netif_init();
    esp_event_loop_create_default();

    wifi_init_config_t cfg = WIFI_INIT_CONFIG_DEFAULT();
    esp_wifi_init(&cfg);
    esp_wifi_set_mode(WIFI_MODE_STA);
    esp_wifi_start();

    esp_now_init();
    esp_now_register_recv_cb(on_recv);

    do_install_tusb(false);
    ESP_LOGI(TAG, "Receiver ready, waiting for device descriptors...");

    while (1) {
        ulTaskNotifyTake(pdTRUE, portMAX_DELAY);
        ESP_LOGI(TAG, "Real descriptors received, reinstalling TinyUSB...");
        do_install_tusb(true);
    }
}

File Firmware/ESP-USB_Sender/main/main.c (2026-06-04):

#include <stdio.h>
#include <string.h>
#include "esp_err.h"
#include "esp_log.h"
#include "esp_now.h"
#include "esp_wifi.h"
#include "freertos/FreeRTOS.h"
#include "freertos/queue.h"
#include "freertos/task.h"
#include "nvs_flash.h"
#include "usb/hid_host.h"
#include "usb/usb_host.h"

static const char *TAG = "sender";

static uint8_t receiver_mac[] = {0xA0, 0xF2, 0x62, 0xE2, 0xE5, 0x18};

#define PKT_DEVICE_DESC 0xFD
#define PKT_CONFIG_DESC 0xFE
#define PKT_HID_REPORT  0xFF

static usb_host_client_handle_t desc_client_hdl = NULL;

QueueHandle_t app_event_queue = NULL;

typedef enum {
    APP_EVENT_HID_HOST
} app_event_group_t;

typedef struct {
    app_event_group_t event_group;
    struct {
        hid_host_device_handle_t handle;
        hid_host_driver_event_t event;
        void *arg;
    } hid_host_device;
} app_event_queue_t;

static void on_sent(const esp_now_send_info_t *info, esp_now_send_status_t status)
{
    ESP_LOGI(TAG, "Send status: %s", status == ESP_NOW_SEND_SUCCESS ? "OK" : "FAIL");
}

static void send_descriptors(uint8_t dev_addr)
{
    usb_device_handle_t dev_hdl;
    if (usb_host_device_open(desc_client_hdl, dev_addr, &dev_hdl) != ESP_OK) {
        ESP_LOGE(TAG, "Failed to open device at addr %d", dev_addr);
        return;
    }

    const usb_device_desc_t *dev_desc;
    if (usb_host_get_device_descriptor(dev_hdl, &dev_desc) == ESP_OK) {
        uint8_t pkt[19];
        pkt[0] = PKT_DEVICE_DESC;
        memcpy(&pkt[1], dev_desc, 18);
        esp_now_send(receiver_mac, pkt, 19);
        ESP_LOGI(TAG, "Sent device descriptor (VID=%04X PID=%04X)",
                 dev_desc->idVendor, dev_desc->idProduct);
        vTaskDelay(pdMS_TO_TICKS(10));
    }

    const usb_config_desc_t *cfg_desc;
    if (usb_host_get_active_config_descriptor(dev_hdl, &cfg_desc) == ESP_OK) {
        const uint8_t *data = (const uint8_t *)cfg_desc;
        uint16_t total_len = cfg_desc->wTotalLength;
        uint8_t chunk_size = 247;
        uint8_t total_chunks = (total_len + chunk_size - 1) / chunk_size;

        ESP_LOGI(TAG, "Sending config descriptor (%d bytes, %d chunks)", total_len, total_chunks);

        for (uint8_t i = 0; i < total_chunks; i++) {
            uint16_t offset = i * chunk_size;
            uint8_t len = (offset + chunk_size > total_len) ? (total_len - offset) : chunk_size;
            uint8_t pkt[250];
            pkt[0] = PKT_CONFIG_DESC;
            pkt[1] = i;
            pkt[2] = total_chunks;
            memcpy(&pkt[3], &data[offset], len);
            esp_now_send(receiver_mac, pkt, len + 3);
            ESP_LOGI(TAG, "Sent config chunk %d/%d (%d bytes)", i + 1, total_chunks, len);
            vTaskDelay(pdMS_TO_TICKS(10));
        }
    }

    usb_host_device_close(desc_client_hdl, dev_hdl);
}

static void desc_client_event_cb(const usb_host_client_event_msg_t *msg, void *arg)
{
    if (msg->event == USB_HOST_CLIENT_EVENT_NEW_DEV) {
        ESP_LOGI(TAG, "New device at addr %d", msg->new_dev.address);
        send_descriptors(msg->new_dev.address);
    }
}

static void desc_client_task(void *arg)
{
    const usb_host_client_config_t client_config = {
        .is_synchronous = false,
        .max_num_event_msg = 5,
        .async = {
            .client_event_callback = desc_client_event_cb,
            .callback_arg = NULL,
        },
    };
    ESP_ERROR_CHECK(usb_host_client_register(&client_config, &desc_client_hdl));

    while (true) {
        usb_host_client_handle_events(desc_client_hdl, portMAX_DELAY);
    }
}

void hid_host_interface_callback(hid_host_device_handle_t hid_device_handle,
                                 const hid_host_interface_event_t event,
                                 void *arg)
{
    uint8_t data[64] = {0};
    size_t data_length = 0;

    switch (event) {
    case HID_HOST_INTERFACE_EVENT_INPUT_REPORT:
        ESP_ERROR_CHECK(hid_host_device_get_raw_input_report_data(
            hid_device_handle, data, 64, &data_length));
        ESP_LOGI(TAG, "HID report (%d bytes): %02X %02X %02X %02X %02X %02X %02X %02X",
                 (int)data_length, data[0], data[1], data[2], data[3],
                 data[4], data[5], data[6], data[7]);
        esp_now_send(receiver_mac, data, data_length);
        break;
    case HID_HOST_INTERFACE_EVENT_DISCONNECTED:
        ESP_LOGI(TAG, "HID Device DISCONNECTED");
        ESP_ERROR_CHECK(hid_host_device_close(hid_device_handle));
        break;
    case HID_HOST_INTERFACE_EVENT_TRANSFER_ERROR:
        ESP_LOGI(TAG, "HID Device TRANSFER_ERROR");
        break;
    default:
        break;
    }
}

void hid_host_device_event(hid_host_device_handle_t hid_device_handle,
                           const hid_host_driver_event_t event, void *arg)
{
    hid_host_dev_params_t dev_params;
    ESP_ERROR_CHECK(hid_host_device_get_params(hid_device_handle, &dev_params));

    switch (event) {
    case HID_HOST_DRIVER_EVENT_CONNECTED:
        ESP_LOGI(TAG, "HID Device CONNECTED (proto=%d)", dev_params.proto);
        const hid_host_device_config_t dev_config = {
            .callback = hid_host_interface_callback,
            .callback_arg = NULL
        };
        if (dev_params.proto != HID_PROTOCOL_NONE) {
            ESP_ERROR_CHECK(hid_host_device_open(hid_device_handle, &dev_config));

            size_t desc_len = 0;
            uint8_t *desc = hid_host_get_report_descriptor(hid_device_handle, &desc_len);
            if (desc && desc_len > 0 && desc_len <= 248) {
                uint8_t pkt[250];
                pkt[0] = PKT_HID_REPORT;
                pkt[1] = dev_params.proto;
                memcpy(&pkt[2], desc, desc_len);
                esp_now_send(receiver_mac, pkt, desc_len + 2);
                ESP_LOGI(TAG, "Sent HID report descriptor proto=%d (%d bytes)",
                         dev_params.proto, (int)desc_len);
                vTaskDelay(pdMS_TO_TICKS(10));
            }

            if (HID_SUBCLASS_BOOT_INTERFACE == dev_params.sub_class) {
                ESP_ERROR_CHECK(hid_class_request_set_protocol(
                    hid_device_handle, HID_REPORT_PROTOCOL_BOOT));
                if (HID_PROTOCOL_KEYBOARD == dev_params.proto) {
                    ESP_ERROR_CHECK(hid_class_request_set_idle(hid_device_handle, 0, 0));
                }
            }
            ESP_ERROR_CHECK(hid_host_device_start(hid_device_handle));
        }
        break;
    default:
        break;
    }
}
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

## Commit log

2026-06-04 format bom
    [bom.csv]
2026-06-04 renaming 1st bom
2026-06-04 making V2
    [ESP-USB.kicad_pcb, ESP-USB.kicad_sch]
2026-06-04 new bom for v2
    [bom.csv]
2026-06-04 renaming v1 and v2
    [bom-V1.csv, bom-V2.csv, bom.csv]
2026-06-13 making V3
    [ESP-USB.kicad_pcb, ESP-USB.kicad_sch, bom-V3.csv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]
2026-06-13 adding v3 pcb in better
2026-06-13 adding v3 schematics
